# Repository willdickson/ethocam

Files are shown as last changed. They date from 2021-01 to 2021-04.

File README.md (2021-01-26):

# ethocam 
Design files for ethocam remote camera system

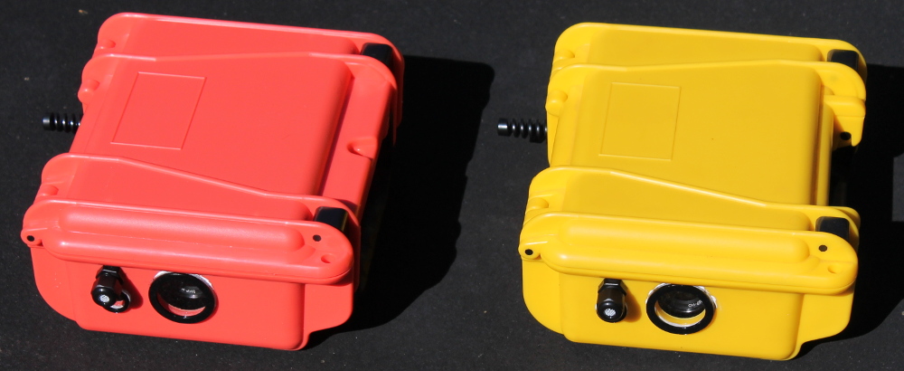
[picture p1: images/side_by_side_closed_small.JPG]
side_by_side_closed

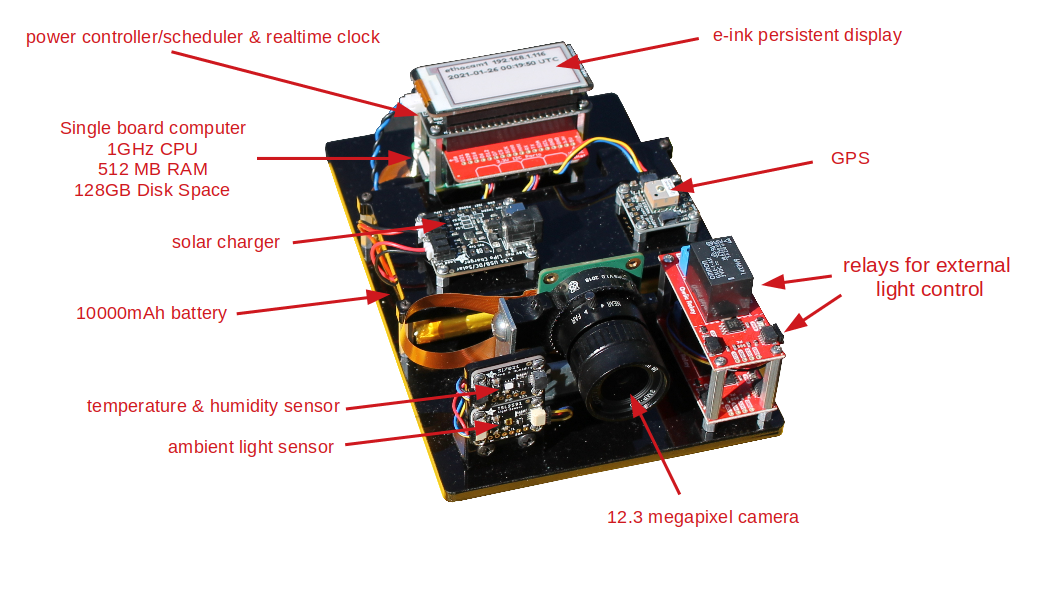
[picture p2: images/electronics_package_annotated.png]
electronics_package_annotated

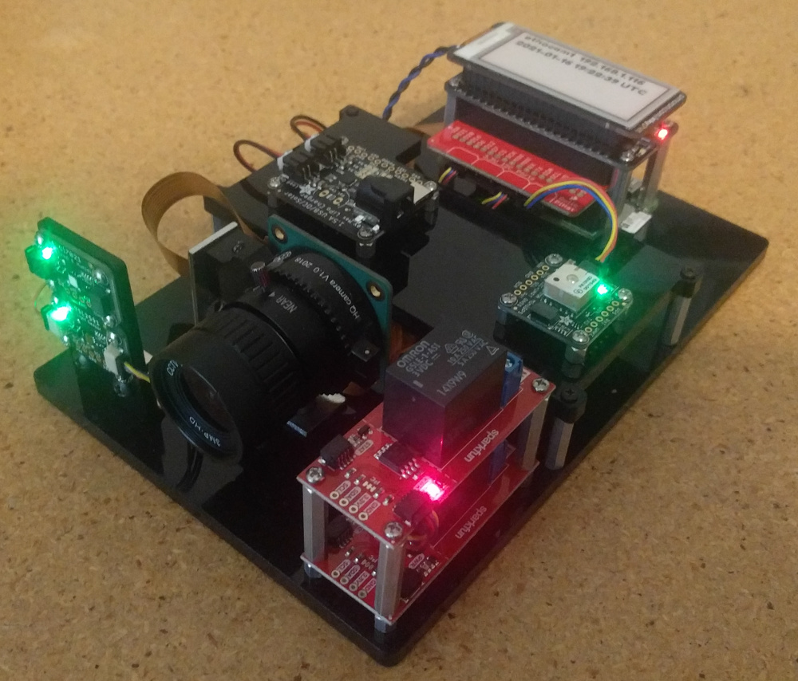
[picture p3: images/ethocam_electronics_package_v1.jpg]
electronics_package_running


# License: 
Creative Commons Attribution 4.0 International CC BY 4.0

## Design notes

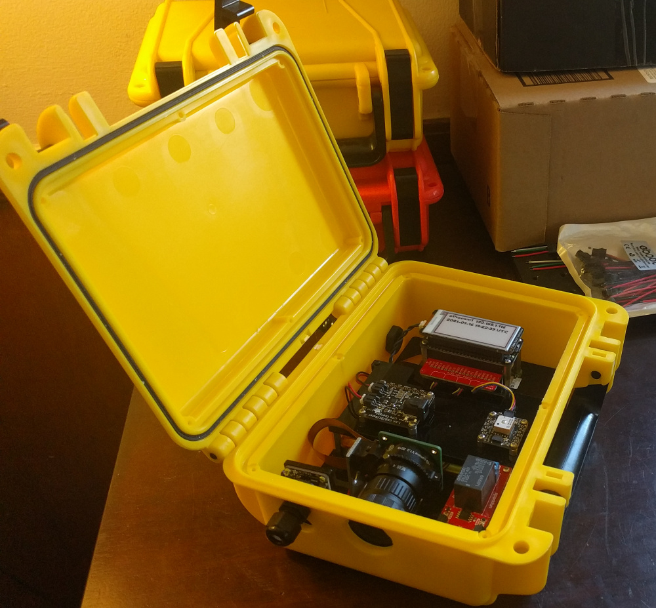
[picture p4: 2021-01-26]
images/ethocam_enclosure.jpg

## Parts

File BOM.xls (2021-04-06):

Item # | Qty | Descripton | Vendor | PN | Unit Cost | Cost
1 | 1 | Witty Pi 3 Mini: Realtime Clock and Power Management for RPI | UUGear or Chicago Electronic Distributors | C1421 | $19.99 | $19.99
2 | 1 | Raspberry Pi Zero W | PiShop.us/adafruit | 808/3400 | $10.00 | $10.00
3 | 1 | Raspberry Pi HQ Camera | PiShop.us/adafruit | 697-1/4561 | $50.00 | $50.00
4 | 1 | 6mm Wide Angle Lens for Raspberry Pi HQ Camera | PiShop.us | 877-1 | $31.25 | $31.25
5 | 1 | Pimoroni Inky pHAT for Raspberry Pi - 3 Color eInk Display | Adafruit | 3743 | $26.50 | $26.50
6 | 1 | SparkFun Qwiic / STEMMA QT HAT for Raspberry | Adafruit | 4688 | $7.50 | $7.50
7 | 1 | Adafruit Mini GPS PA1010D - UART and I2C - STEMMA QT | Adafruit | 4415 | $29.95 | $29.95
8 | 1 | Adafruit Universal USB / DC / Solar Lithium Ion/Polymer charger | Adafruit | 4755 | $9.95 | $9.95
9 | 1 | Adafruit Si7021 Temperature & Humidity Sensor Breakout Board | Adafruit | 3251 | $8.95 | $8.95
10 | 1 | Adafruit TSL2591 High Dynamic Range Digital Light Sensor | Adafruit | 1980 | $6.95 | $6.95
11 | 2 | STEMMA QT / Qwiic JST SH 4-Pin Cable - 50mm Long | Adafruit | 4399 | $0.95 | $1.90
12 | 2 | STEMMA QT / Qwiic JST SH 4-Pin Cable - 200mm Long | Adafruit | 4401 | $0.95 | $1.90
12 | 2 | Stackable 0.100″ Female Header: 2x20-Pin, Straight | Pololu | 2748 | $2.25 | $4.50
13 | 1 | Pololu 5V Step-Up Voltage Regulator U3V12F5 | Pololu | 2115 | $3.49 | $3.49
14 | 1 | Pololu 12V Step-Up Voltage Regulator U3V12F12 | Pololu | 2117 | $3.49 | $3.49
15 | 2 | SparkFun Qwiic Single Relay | Sparkfun | 15093 | $12.95 | $25.90
16 | 1 | DC 3.7V 10000mAh 1160100 Lipo Battery Rechargeable 2P PH 2.0mm | Amazon | AKZYTUE PL1160100 | $18.99 | $18.99
17 | 1 | 6 Watt 6 Volt Solar Panel | voltaicsystems | P106 | $59.00 | $59.00
18 | 1 | Solar Panel Bracket – Medium | voltaicsystems | K102 | $9.00 | $9.00
19 | 1 | Panel Post Nuts - ABS Plastic | voltaicsystems | POSTNUTS-ABS-4 | $2.00 | $2.00
20 | 1 | Female 3.5x1.1mm - Extension with Leads | voltaicsystems | W045 | $4.00 | $4.00
21 | 1 | 5.5x2.1mm – 3.5x1.1mm | voltaicsystems | NA | $6.00 | $6.00
22 | 1 | Serpac CASE PLSTC BLACK 8.7"L X 7.45"W | Digikey | SR-R120-B-ND | $22.81 | $22.81
 |  |  |  |  | Total | $364.02
 |  | Optional Items
 |  | 3.5x1.1mm Extension Cable - 4 Foot | voltaicsystems | NA | $6.00
 |  | 3.5x1.1mm Extension Cable - 10 Foot | voltaicsystems | NA | $10.00

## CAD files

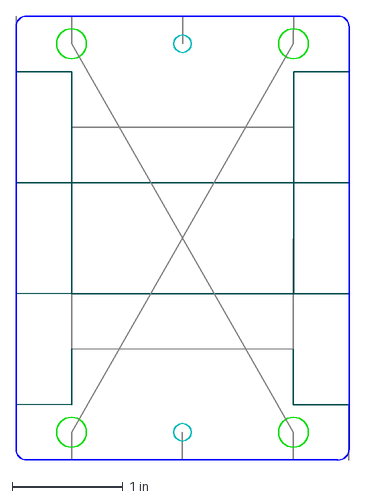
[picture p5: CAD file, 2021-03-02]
enclosure/cnc/enclosure_bottom_holes/external_mount_plate.dxf
3.00 x 4.00 in

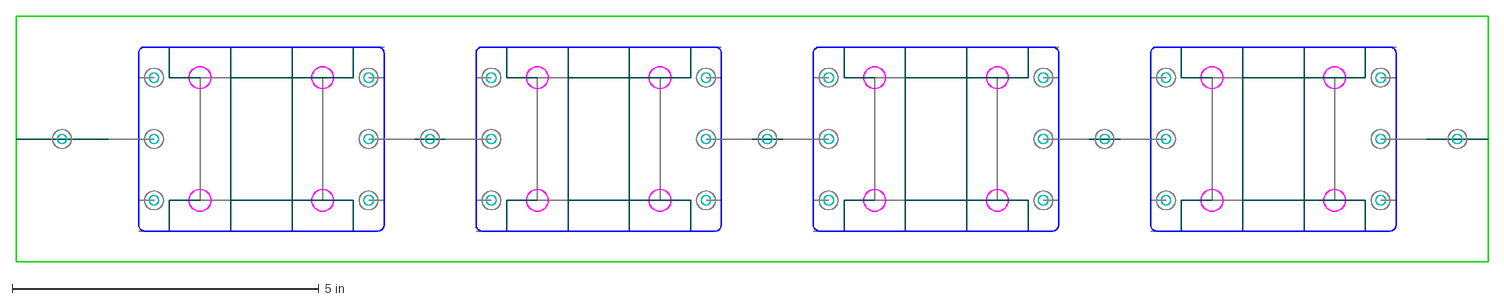
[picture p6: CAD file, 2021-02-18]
enclosure/cnc/external_mount_plate/external_mount_plate.dxf
24.0 x 4.00 in

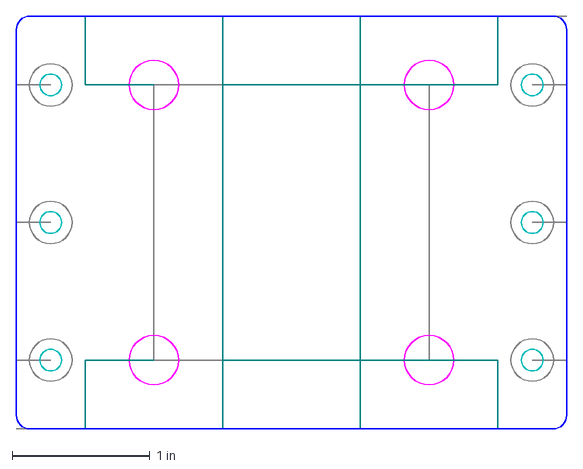
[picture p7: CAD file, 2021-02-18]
enclosure/external_mount_plate.dxf
4.00 x 3.00 in

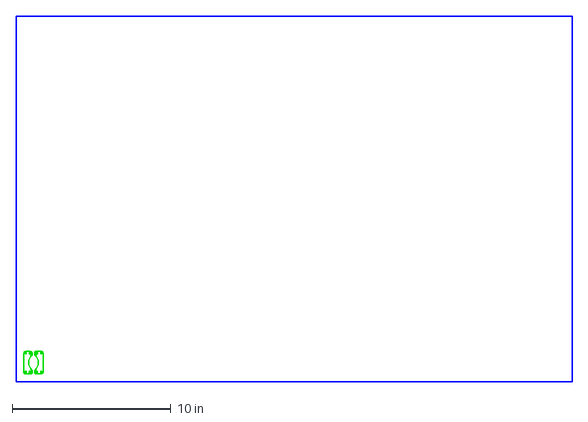
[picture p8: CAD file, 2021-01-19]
enclosure/lasercut/camera_mount_plate/camera_mount_plate.dxf
35.0 x 23.0 in

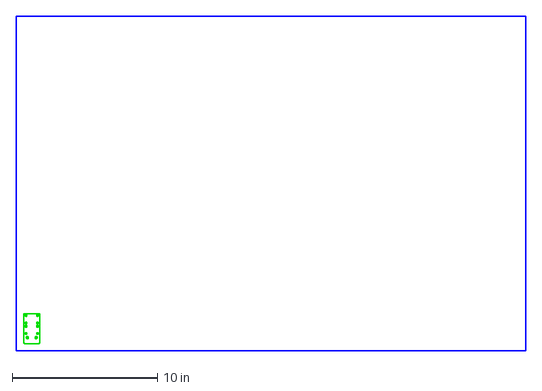
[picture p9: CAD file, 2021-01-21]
enclosure/lasercut/internal_mount_plates/3mm/mount_plates.dxf
35.0 x 23.0 in

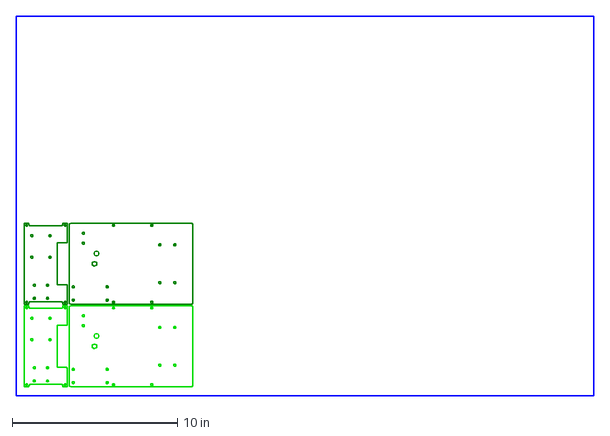
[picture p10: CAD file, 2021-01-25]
enclosure/lasercut/internal_mount_plates/6mm/mount_plates.dxf
35.0 x 23.0 in

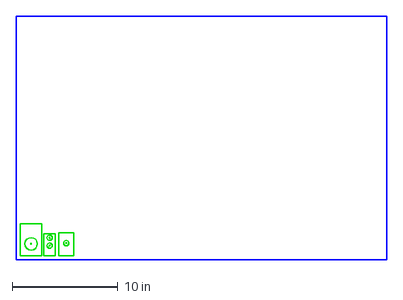
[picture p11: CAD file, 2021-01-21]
enclosure/lasercut/jigs/drill_jigs.dxf
35.0 x 23.0 in

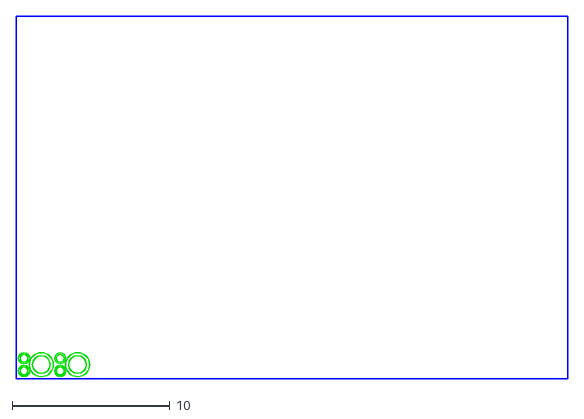
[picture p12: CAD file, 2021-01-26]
enclosure/lasercut/windows/1p5mm_black/windows.dxf
35.0 x 23.0

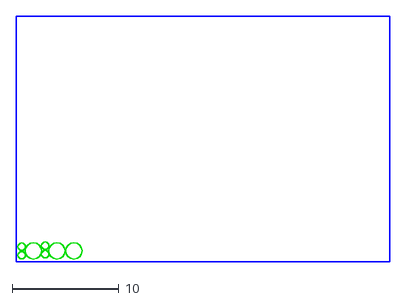
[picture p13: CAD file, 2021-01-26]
enclosure/lasercut/windows/1p5mm_clear/windows.dxf
35.0 x 23.0

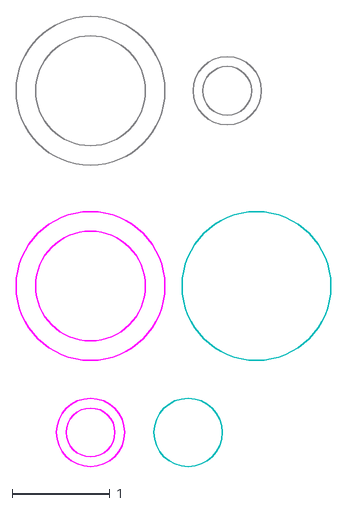
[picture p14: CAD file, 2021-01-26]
enclosure/windows.dxf
3.23 x 4.61

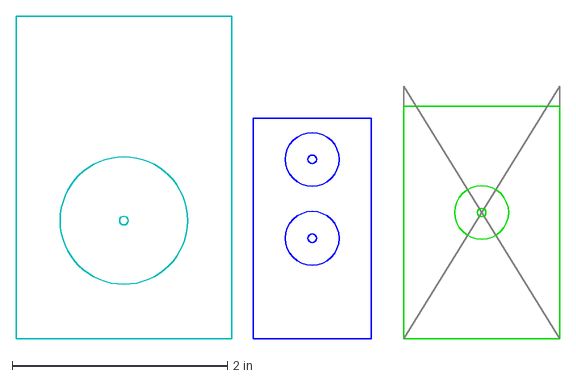
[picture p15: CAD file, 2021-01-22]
enclosure/drill_jigs.dxf
5.05 x 3.00 in

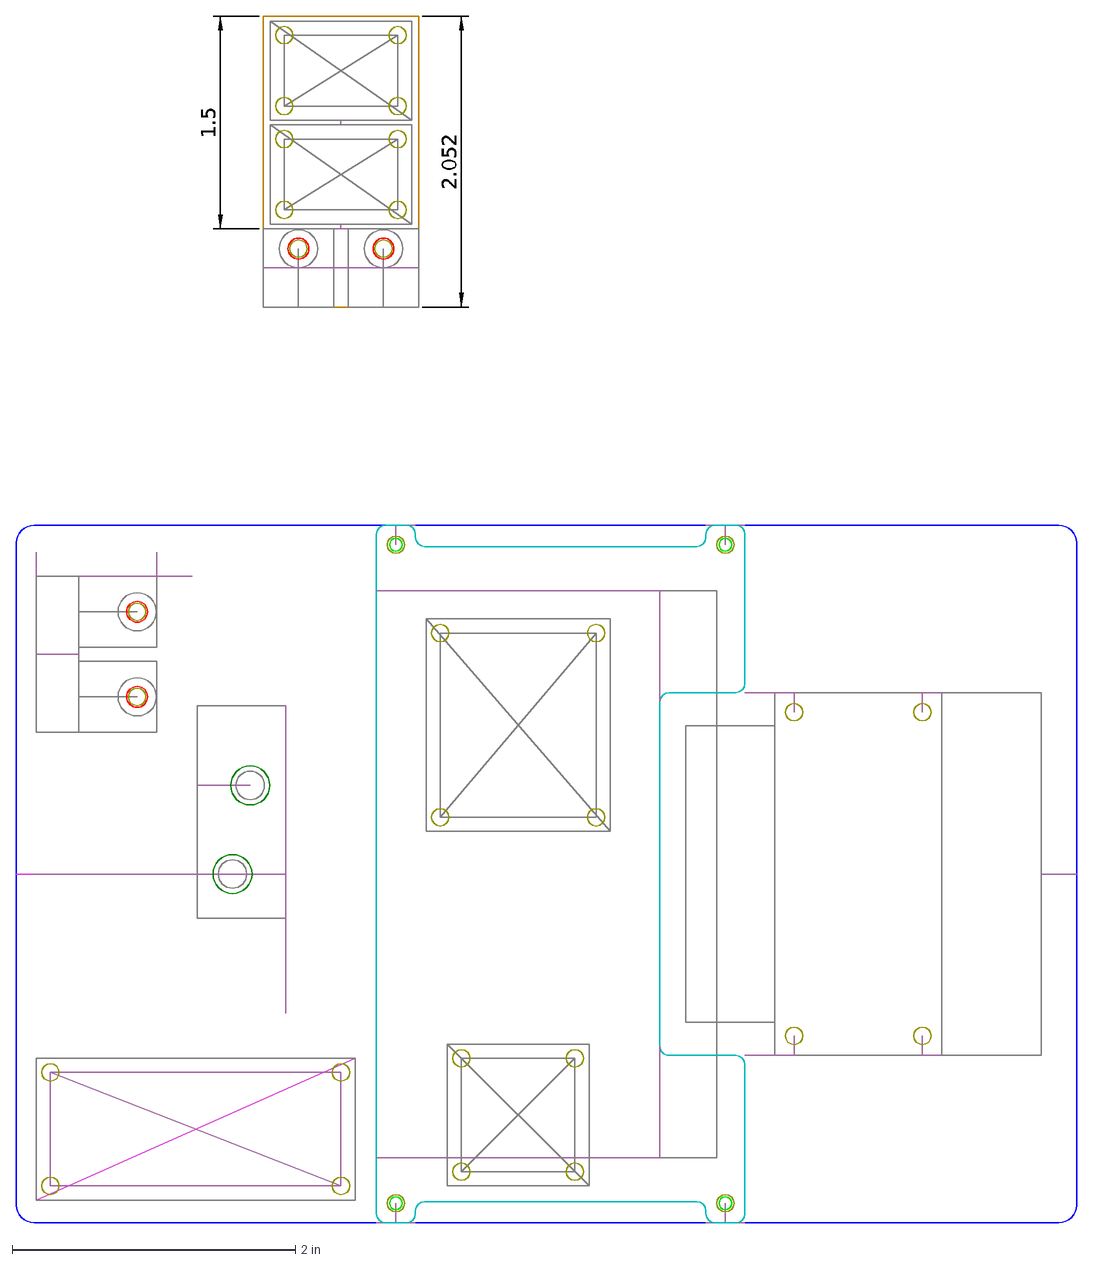
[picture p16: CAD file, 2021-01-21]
enclosure/internal_mount_plates.dxf
1.5
2.052

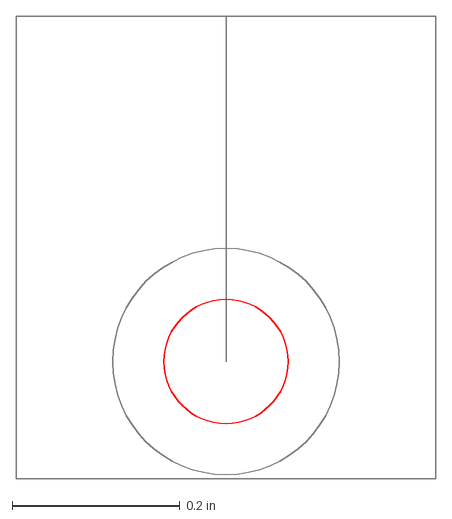
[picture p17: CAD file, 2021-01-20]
enclosure/right_angle_bracket_6-32.dxf
0.5 x 0.552 in

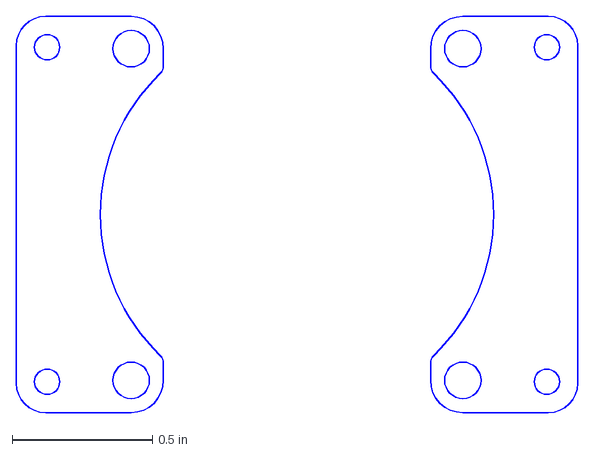
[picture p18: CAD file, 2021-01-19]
enclosure/camera_mount_plate.dxf
2.00 x 1.41 in

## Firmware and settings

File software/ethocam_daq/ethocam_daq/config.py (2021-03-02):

import os
import configparser


class Config(configparser.ConfigParser):

    def __init__(self):
        super().__init__()
        config_filename = os.path.join(os.path.sep,'home', 'pi', '.config', 'ethocam')
        self.read(config_filename)

    def print(self):
        for section in self.sections():
            print(section)
            for k,v in self[section].items():
                print(f'  {k} = {v}')

    def dict(self):
        config_dict = {}
        for section in self.sections():
            config_dict[section] = dict(self[section])
        return config_dict



# -----------------------------------------------------------------------------
if __name__ == '__main__':
    config = Config()
    config.print()
    print(config.dict())

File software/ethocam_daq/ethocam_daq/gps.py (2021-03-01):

import board
import adafruit_gps


class GPS:

    def __init__(self,config):
        self.max_attempt = config['GPS'].getint('max_attempt')
        self.dt = config['GPS'].getfloat('dt') 
        self.device = adafruit_gps.GPS_GtopI2C(board.I2C(), debug=False)  
        # Turn on the basic GGA and RMC info 
        self.device.send_command(b"PMTK314,0,1,0,1,0,0,0,0,0,0,0,0,0,0,0,0,0,0,0")
        # Set update rate to once a second (1hz) 
        self.device.send_command(b"PMTK220,1000")

    def read(self):
        data = {}
        attempt_cnt = 0
        while attempt_cnt < self.max_attempt:
            self.device.update()
            if self.device.has_fix:
                break
            else:
                attempt_cnt += 1
        if self.device.has_fix:
            data['latitude'] = self.device.latitude
            data['longitutde'] = self.device.longitude
            data['fix_quality'] = self.device.fix_quality
            if self.device.satellites is not None:
                data['satellites'] = self.device.satellites
            if self.device.altitude_m is not None:
                data['altitude_m'] = self.device.altitude_m
            if self.device.speed_knots is not None:
                data['speed_knots'] = self.device.speed_knots
            if self.device.track_angle_deg is not None:
                data['track_angle_deg'] = self.device.track_angle_deg
            if self.device.horizontal_dilution is not None:
                data['horizontal_dilution'] = self.device.horizontal_dilution
            if self.device.height_geoid is not None:
                data['height_geoid'] = self.device.height_geoid
        return data

# -----------------------------------------------------------------------------------
if __name__ == '__main__':

    import configparser
    config = configparser.ConfigParser()
    config['GPS'] = {'max_attempt':  10, 'dt':  0.1}


    gps = GPS(config)
    data = gps.read()
    for k,v in data.items():
        print(f'{k}: {v}')

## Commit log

2021-01-19 Added laser cutting files for camera mount.
2021-01-19 Project creation.
    [camera_mount_plate.dxf]
2021-01-20 Removed old camera_mount_plate directory.
2021-01-20 Added laser cutting files for enclosure mount plates.
    [mount_plates.dxf]
2021-01-20 Completed initial design of insert plates for enclosure.
    [mount_plates.dxf, right_angle_bracket_6-32.dxf]
2021-01-21 Fixed heat set insert hole sizes for recut.
    [mount_plates.dxf]
2021-01-21 Added modified lasercutting files.
    [mount_plates.dxf]
2021-01-21 Added laser cutting files for hole jigs.
    [drill_jigs.dxf]
2021-01-22 Added design for hole jigs.
    [drill_jigs.dxf]
2021-01-22 Added hole for solar panel coord grip.
    [drill_jigs.dxf]
2021-01-25 Added lasercutting files for windows.
    [mount_plates.dxf]
2021-01-26 Added window designs.
    [windows.dxf]
2021-01-26 Fixed issue with window size.
    [windows.dxf]
2021-01-26 Added additional laser cutting files.
2021-02-18 Added design of external_mount_plate for enclosure.
    [BOM.xls, external_mount_plate.dxf, internal_mount_plates.dxf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]
2021-02-18 Added gcode for cutting external mount plates on cnc router.
    [external_mount_plate.dxf]
2021-03-01 Fixed error in logging temperature and humidity data.
    [cmd_line.py]
2021-03-02 Added cnc generation (py2gcode) and gcode for machine hole on the bottom-outside of the enclosure.
    [external_mount_plate.dxf]
2021-03-02 Fixed issues with file transfer when running as root.
    [cmd_line.py, config.py, file_transfer.py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]
2021-03-04 Fixed debugged some issues.
    [cmd_line.py, display.py, file_transfer.py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]
2021-04-06 Updated bill of materials.
    [BOM.xls]
2021-05-06 Added enabled option to Network in config. Added additional camera settings.
2021-07-16 Modifided to display battery voltage, added info command, added video options.
2024-03-08 Added mount plate for ir light.
